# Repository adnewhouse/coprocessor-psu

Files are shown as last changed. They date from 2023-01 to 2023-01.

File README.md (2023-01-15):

# coprocessor-psu

- 6-15V input, 19V output at up to 5A
- Supplies power to onboard vision co-proccesor
- Custom circuit powered by 10A breaker on PDH
- Robust input protection

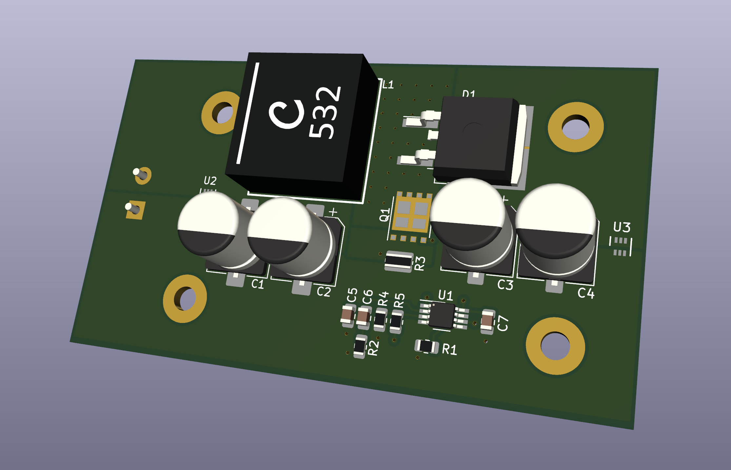
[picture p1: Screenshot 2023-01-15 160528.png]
board


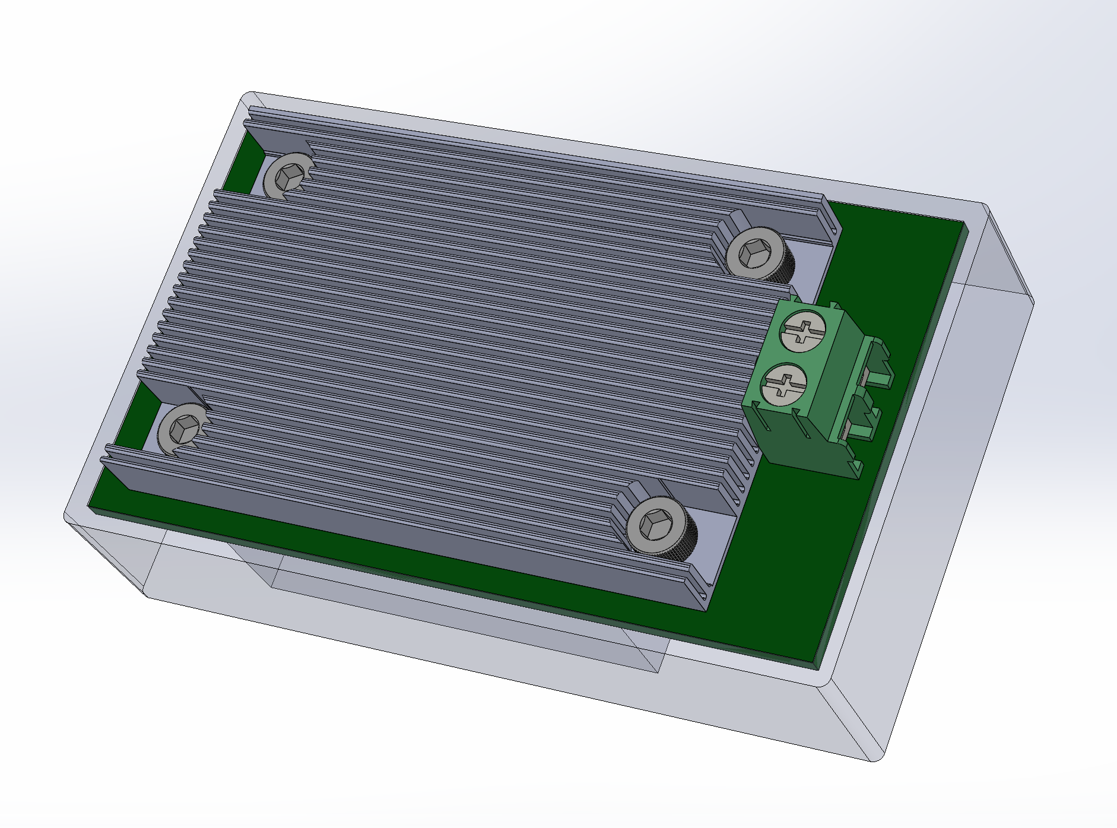
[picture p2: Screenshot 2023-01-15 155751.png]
box


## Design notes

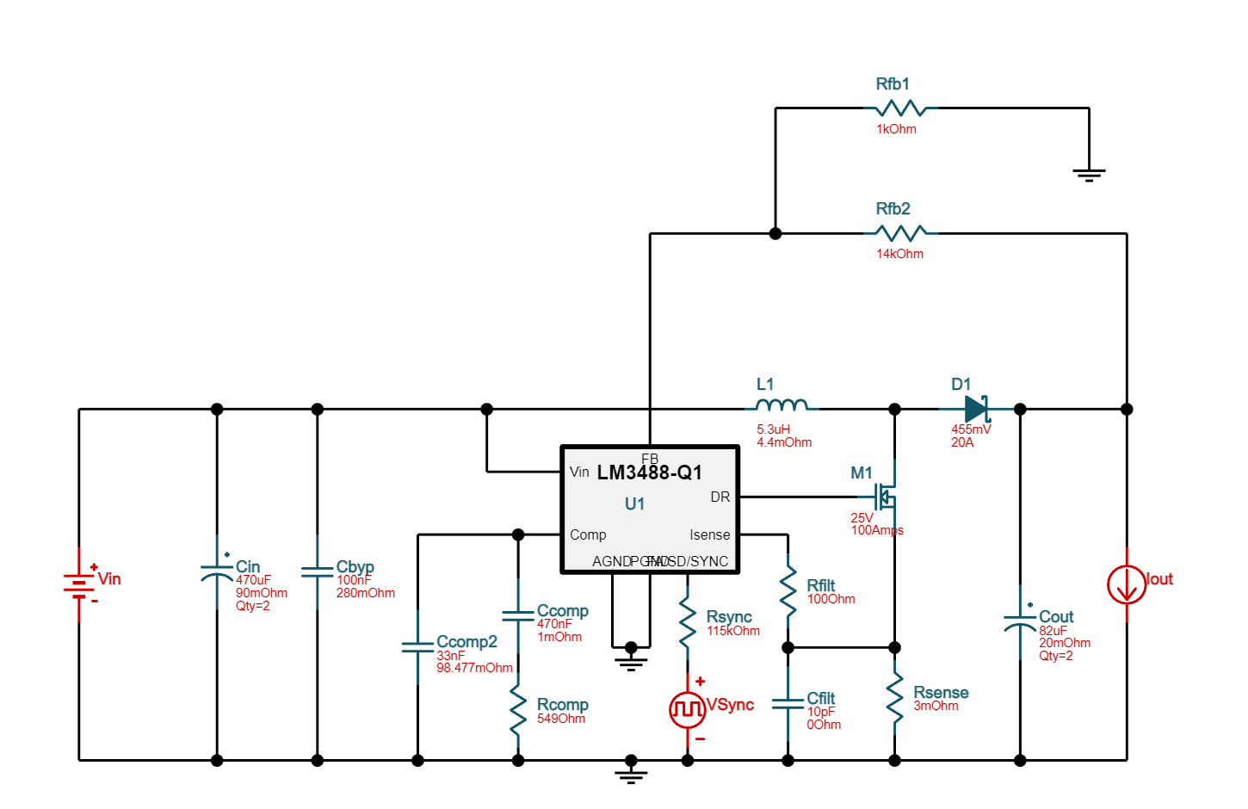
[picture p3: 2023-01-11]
Screenshot 2023-01-11 154840.png

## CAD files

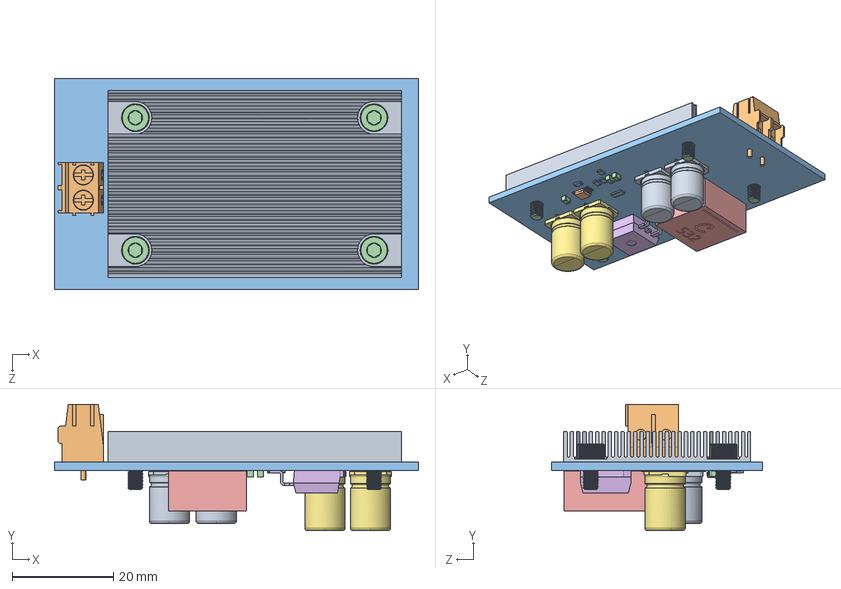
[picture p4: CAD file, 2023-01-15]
3d/Assem.SLDASM
72.0 x 25.0 x 41.8 mm
HEATSINK
SOLID.step
SOLID-0.step x 4
SOLID-1.step x 3
SOLID-2.step
SOLID-3.step
SOLID-4.step x 2
SOLID-5.step
SOLID-6.step x 2
SOLID-7.step
coprocessor-psu PCB.step
90751A110_18-8 Stainless Steel Socket Head Screws x 4

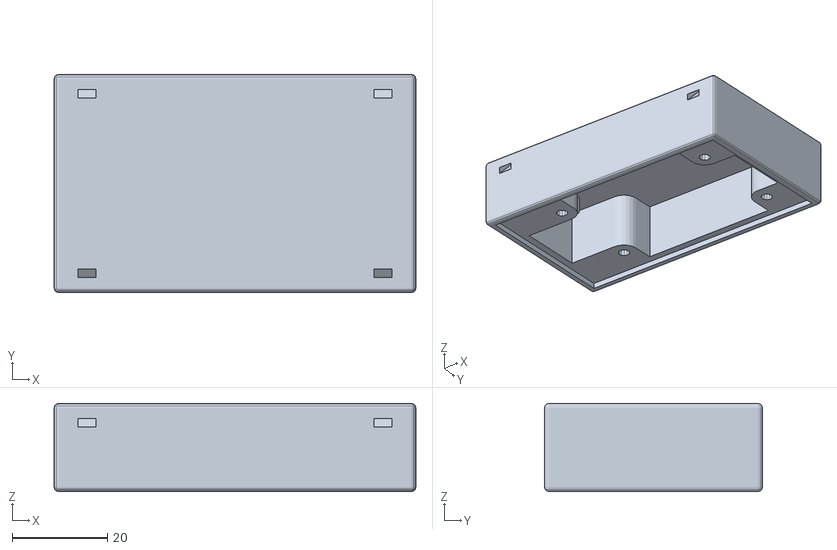
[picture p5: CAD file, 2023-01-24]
3d/case.stl
76.0 x 45.8 x 18.5

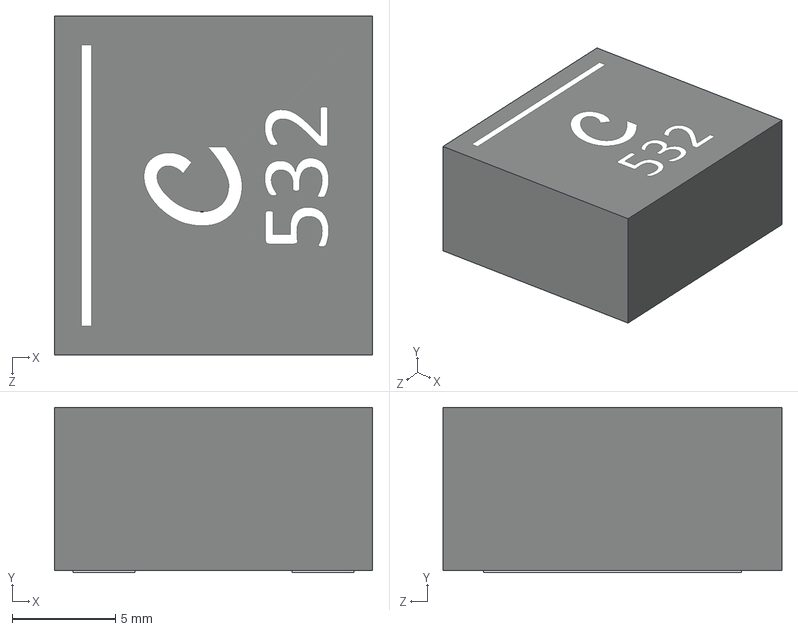
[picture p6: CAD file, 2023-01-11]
Coilcraft-XAL1580-532.step
15.4 x 8.00 x 16.4 mm

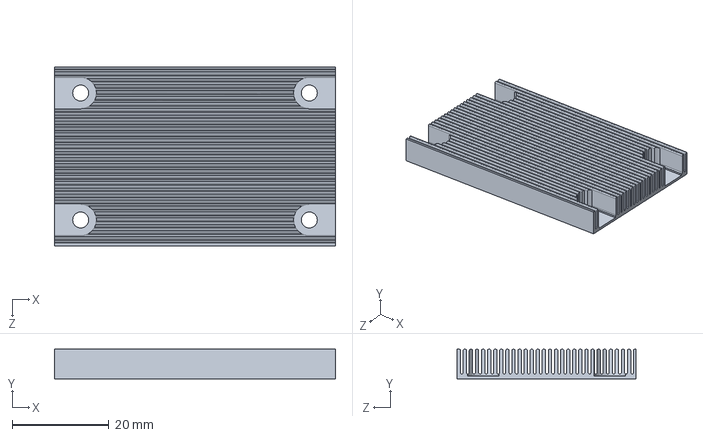
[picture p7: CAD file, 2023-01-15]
3d/HEATSINK.SLDPRT
58.0 x 6.10 x 37.0 mm

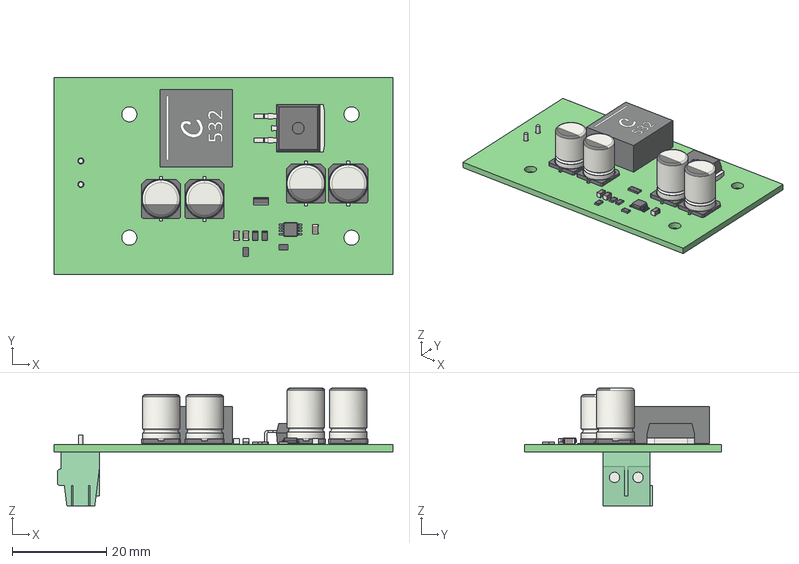
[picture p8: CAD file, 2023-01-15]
3d/coprocessor-psu.step
72.0 x 41.8 x 25.0 mm
coprocessor-psu PCB

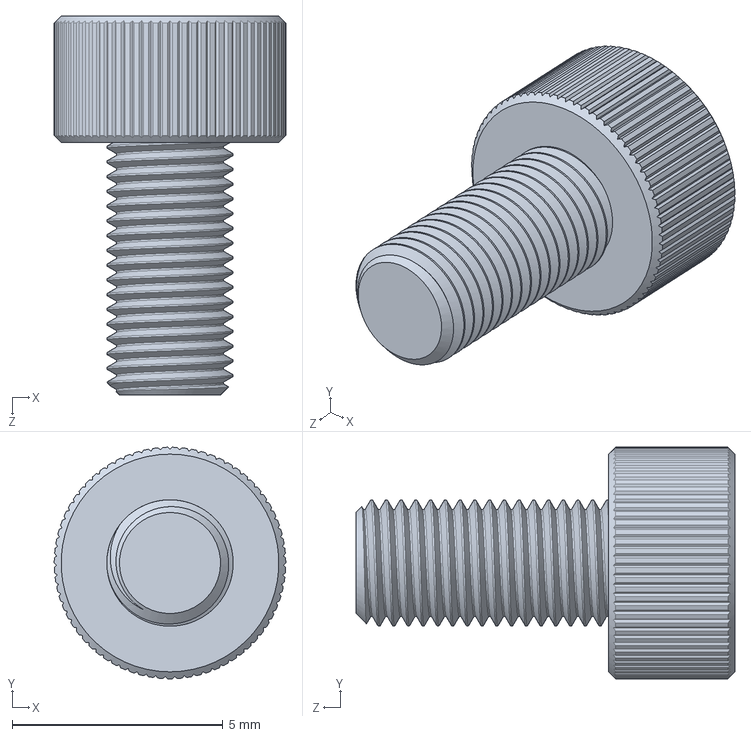
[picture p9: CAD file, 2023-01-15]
3d/90751A110_18-8 Stainless Steel Socket Head Screws.SLDPRT
5.50 x 5.50 x 9.00 mm

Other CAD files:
3d/Assem/90751A110_18-8 Stainless Steel Socket Head Screws.ipt
3d/Assem/Assem.iam
3d/Assem/BOX^Assem.ipt
3d/Assem/Coilcraft-XAL1580-532.step.iam
3d/Assem/HEATSINK.ipt
3d/Assem/OldVersions/90751A110_18-8 Stainless Steel Socket Head Screws.0001.ipt
3d/Assem/OldVersions/Assem.0002.iam
3d/Assem/OldVersions/BOX^Assem.0001.ipt
3d/Assem/OldVersions/HEATSINK.0001.ipt
3d/Assem/SOLID.step.ipt
3d/Assem/coprocessor-psu PCB.step.ipt
3d/Assem/coprocessor-psu.step.iam
3d/CP_Elec_8x10.5.iam
3d/CP_Elec_8x11.9.iam
3d/C_0805_2012Metric.iam
3d/Coilcraft-XAL1580-532.iam
3d/R_0612_1632Metric.iam
3d/R_0805_2012Metric.iam
3d/SOLID.ipt
3d/SOLID_1.ipt
3d/SOLID_2.ipt
3d/SOLID_3.ipt
3d/SOLID_4.ipt
3d/SOLID_5.ipt
3d/SOLID_6.ipt
3d/SOLID_7.ipt
3d/SOLID_8.ipt
3d/TO-263-2.iam
3d/TerminalBlock_Phoenix_PT-1,5-2-5.0-H_1x02_P5.00mm_Horizontal.iam
3d/VSSOP-8_3.0x3.0mm_P0.65mm.iam
3d/case.ipt
3d/coprocessor-psu PCB.ipt
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

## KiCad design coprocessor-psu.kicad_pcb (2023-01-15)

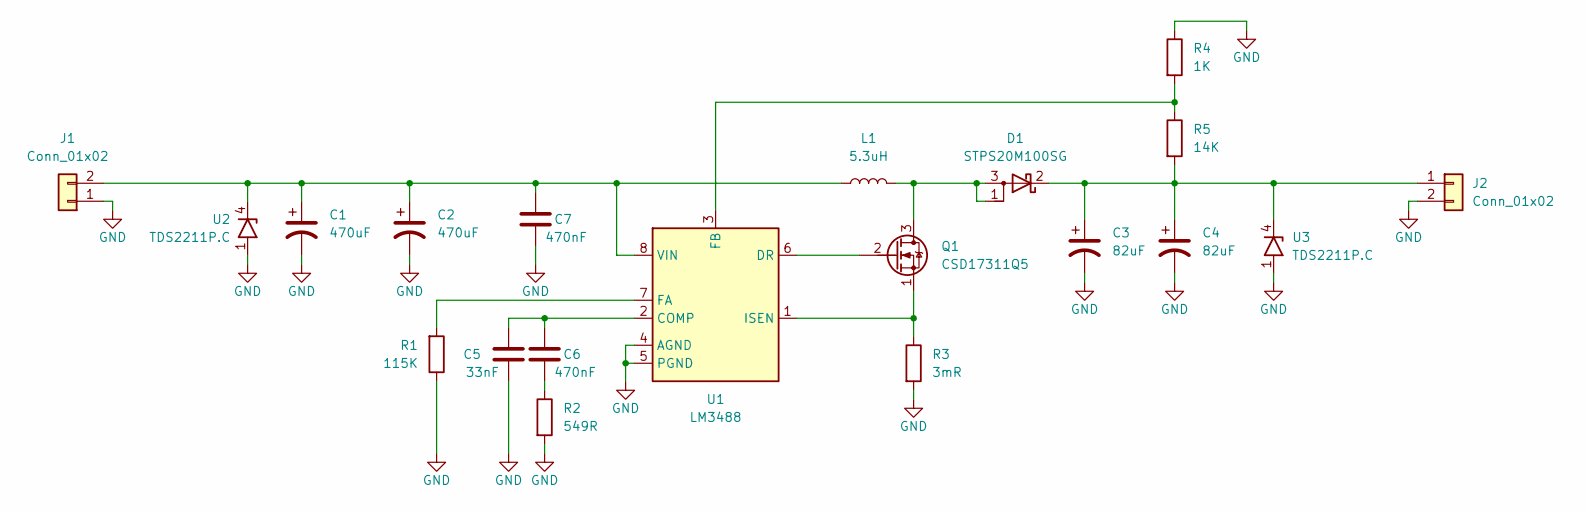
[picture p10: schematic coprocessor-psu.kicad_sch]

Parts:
C1, C2: 470uF; CP_Elec_8x10.5; MPN EEE-FN1E471UV
C3, C4: 82uF; CP_Elec_8x11.9; MPN 35SVPF82M
C5: 33nF; C_0805_2012Metric; MPN CGA4J1C0G2A333J125AE
C6, C7: 470nF; C_0805_2012Metric; MPN CGA4J3X7R1H474K125AE
D1: STPS20M100SG; TO-263-2; MPN STPS20M100SG
J1: Conn_01x02; TerminalBlock_Phoenix_PT-1,5-2-5.0-H_1x02_P5.00mm_Horizontal
J2: Conn_01x02
L1: 5.3uH; XAL1580; MPN XAL1580-532MED
Q1: CSD17311Q5; VSONP-8-1EP_5x6_P1.27mm; MPN CSD17311Q5
R1: 115K; R_0805_2012Metric
R2: 549R; R_0805_2012Metric
R3: 3mR; R_0612_1632Metric; MPN WSL06123L000FEA
R4: 1K; R_0805_2012Metric
R5: 14K; R_0805_2012Metric
U1: LM3488; VSSOP-8_3.0x3.0mm_P0.65mm; MPN LM3488MM
U2, U3: TDS2211P.C; DFN-6_1.6x1.6

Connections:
GND: C1.2, C2.2, C3.2, C4.2, C5.1, C7.1, J1.1, J2.2, R1.1, R2.2, R3.2, R4.1, U1.4 (AGND), U1.5 (PGND), U2.1, U2.2, U2.3, U3.1, U3.2, U3.3
unnamed: C1.1, C2.1, C7.2, J1.2, L1.1, U1.8 (VIN), U2.4, U2.5, U2.6
unnamed: C3.1, C4.1, D1.2 (K), J2.1, R5.2, U3.4, U3.5, U3.6
unnamed: C5.2, C6.2, U1.2 (COMP)
unnamed: C6.1, R2.1
unnamed: D1.1 (A), D1.3 (A), L1.2, Q1.3 (D)
unnamed: Q1.1 (S), R3.1, U1.1 (ISEN)
unnamed: Q1.2 (G), U1.6 (DR)
unnamed: R1.2, U1.7 (FA)
unnamed: R4.2, R5.1, U1.3 (FB)

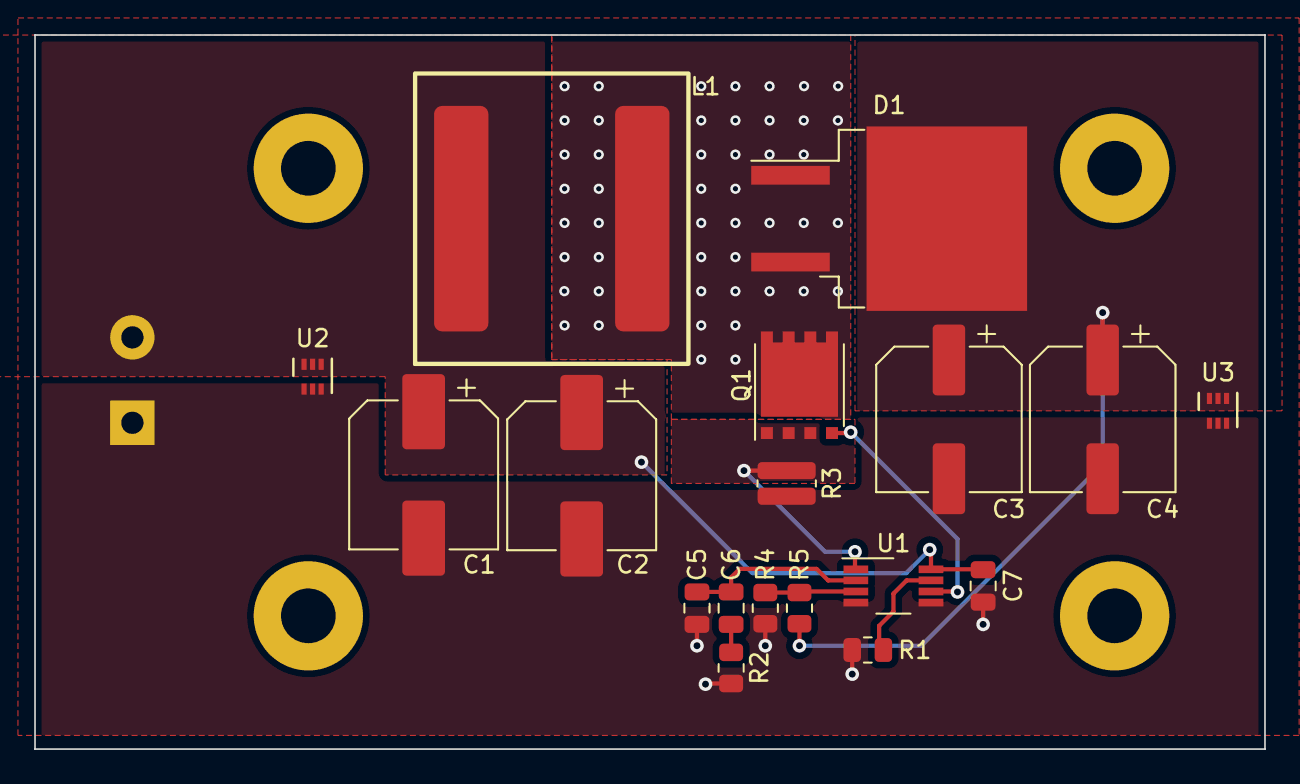
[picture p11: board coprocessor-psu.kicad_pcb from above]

Board: 2 copper layers, 72.0 x 41.8 mm, 19 parts (1 on the bottom side), 10 nets.

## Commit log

2023-01-11 some more details
    [coprocessor-psu.kicad_pcb]
2023-01-15 Add 3d model, finish layout pending type-c plug study
    [90751A110_18-8 Stainless Steel Socket Head Screws.SLDPRT, Assem.SLDASM, HEATSINK.SLDPRT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]
2023-01-24 add 3d models
    [90751A110_18-8 Stainless Steel Socket Head Screws.0001.ipt, 90751A110_18-8 Stainless Steel Socket Head Screws.ipt, Assem.0002.iam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]
